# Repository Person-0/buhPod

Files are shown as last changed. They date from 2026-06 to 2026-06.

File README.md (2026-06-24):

# **buhPod**

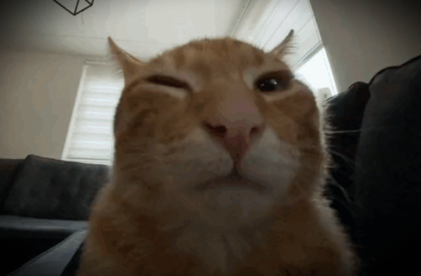
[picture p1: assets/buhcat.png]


A portable, battery-powered music player that supports 3.5mm wired earphones, made under 25$.

## Bill Of Materials
\> View [bom.csv](./bom.csv) (WIP)<br>
Total cost is **~25$**

## CAD Design
- WIP
- View [/CAD directoy](./cad/) for more information

> **Rough assembly**
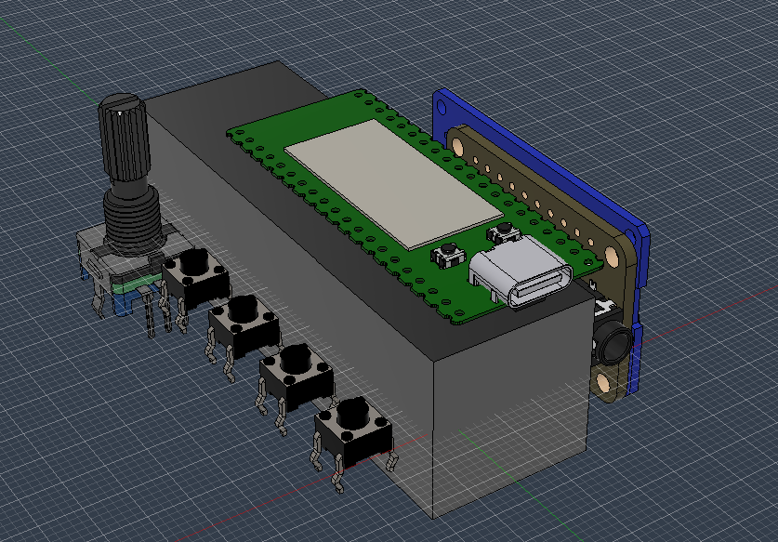
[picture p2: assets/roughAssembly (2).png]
> 

## Schematics

Done in KiCAD: [Schematics folder](./schematics/)

Since there is no PCB (these are all components wired/soldered together), there are no PCB files. <br>
However, you can still open the schematics in KiCAD, by:
- Opening KiCAD
- Clicking **File** (top left) >> **Open Project**
- Navigating to the the repository's saved destination,
- Opening **/schematics** directory
- Selecting the file `buhpod.kicad_pro`

This will open the schematics in KiCAD for easier viewing!<br>
The schematics are as follows:

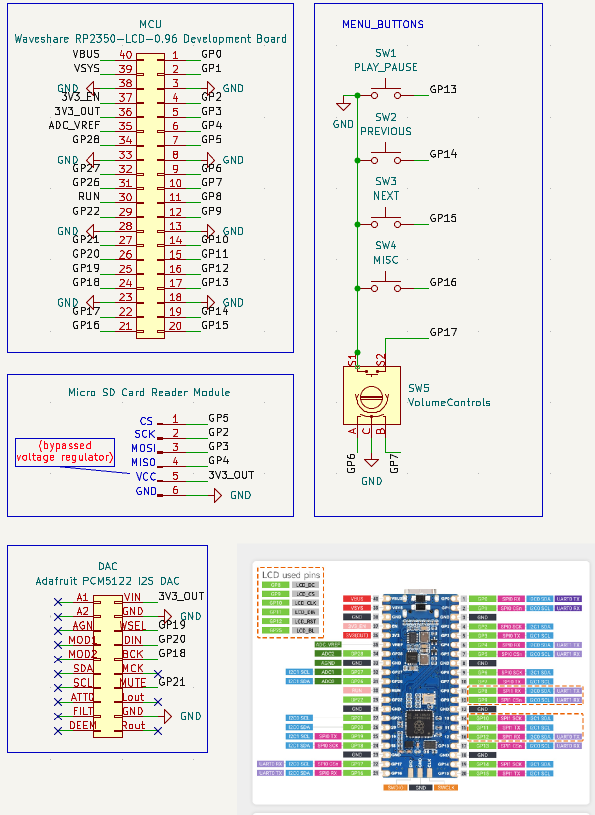
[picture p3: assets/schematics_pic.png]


### Micro SD card regulator bypass

The Micro SD card reader mentioned in the BOM requires **5V** input from **VCC**, but we can only supply **3.3V** from the MCU max as we are powering it via a 18650 3.7V battery and not USB.<br>

Hence, we need to bypass the voltage regulator present on board by powering the board from the following **3.3V pin**:

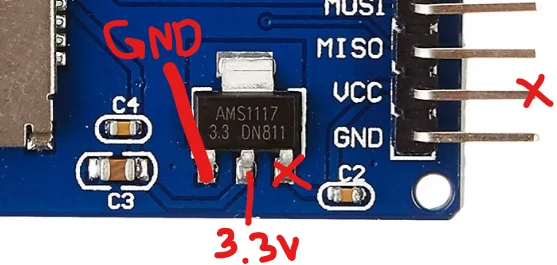
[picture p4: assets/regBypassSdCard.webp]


This bypasses the onboard AMS1117 voltage regulator and is connected to MCU's `3V3_OUT` pin.<br>
This is also mentioned in the schematic for the Micro SD Card reader.

## References
- https://www.waveshare.com/rp2350-lcd-0.96.htm
- https://files.waveshare.com/wiki/RP2350-LCD-0.96/RP2350_LCD_0.96_Schematic.pdf
- https://learn.adafruit.com/adafruit-pcm5122-i2s-dac/downloads
- https://www.instructables.com/Raspberry-Pi-Pico-Micro-SD-Card-Interface/  
- https://circuitdigest.com/microcontroller-projects/raspberry-pi-pico-interfacing-with-rotary-encoder
- https://www.instructables.com/Raspberry-Pi-Pico-and-Rotary-Encoder/

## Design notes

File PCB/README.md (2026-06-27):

# BuhPod PCB

- These are the PCB design files, made using KiCAD.<br>
- This is technically a fork of [Minimal design example](https://datasheets.raspberrypi.com/rp2350/Minimal-KiCAD.zip) provided by raspberrypi, in their [hardware design docs for the RP2350](https://pip-assets.raspberrypi.com/categories/1214-rp2350/documents/RP-008280-DS-1-hardware-design-with-rp2350.pdf).
- It is currently WIP.

## Credits / References
- https://pip-assets.raspberrypi.com/categories/1214-rp2350/documents/RP-008280-DS-1-hardware-design-with-rp2350.pdf
- https://deepbluembedded.com/rp2350-hardware-pcb-design-in-kicad-rp2350-schematic/
- https://macondo.hackclub.com/docs/build-a-devboard

## Licensing

The custom schematic and PCB layout files in this repository are licensed under the MIT License. 

This design is a derivative work based on the "Minimal Design Example" provided by Raspberry Pi Ltd. In accordance with their hardware terms, the reference templates are used solely in conjunction with Raspberry Pi silicon (RP2040/RP2350), and the original reference design is provided "AS IS" without any warranties.

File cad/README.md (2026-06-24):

## **buhPod** Design Files

> Everything was designed in Autodesk Fusion 360

## Rough Assembly

This is a **rough assembly** of components I made after hard labour. <br>
It is only for reference and will be enclosed in a cuboidal enclosure that is current work-in-progress.
> [Click to view **`roughAssembly.stl`**](./roughAssembly.stl)

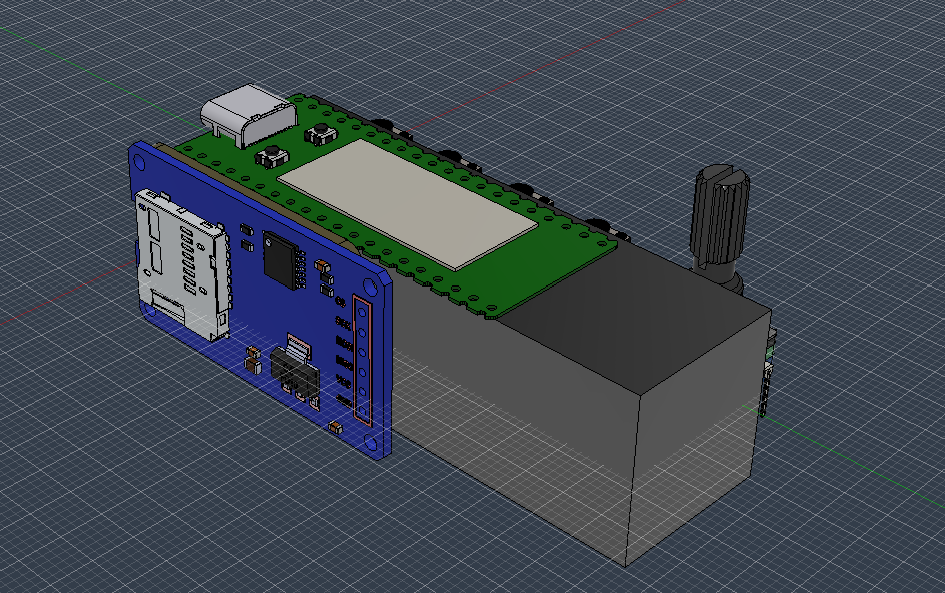
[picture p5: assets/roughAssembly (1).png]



### CAD Model Credits
- https://files.waveshare.com/wiki/RP2350-LCD-0.96/RP2350_LCD_0.96_STEP.zip
- https://grabcad.com/library/micro-sd-card-reader-module-1
- https://github.com/adafruit/Adafruit_CAD_Parts/blob/main/6421%20PCM5122%20I2S%20DAC/6421%20PCM5122%20I2S%20DAC.step
- https://grabcad.com/library/button-6x6x4-3-6x6x5-6x6x6-1
- https://grabcad.com/library/rotary-encoder-17

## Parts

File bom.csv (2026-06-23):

 |  | buhPod: BOM
 |  |  |  |  | (INR) |  | (INR)
S.No | Product Name | Product Description | Product Link | Product Info Link | Unit Price | Quantity | Running Total |  | CAD models
1 | Waveshare RP2350-LCD-0.96 Development Board | MCU (RP2350) with 0.96'' LCD display | https://robu.in/product/waveshare-rp2350-lcd-0-96-development-board-with-0-96inch-lcd-display-based-on-rp2350a-dual-core-dual-architecture-microcontroller/ | https://www.waveshare.com/rp2350-lcd-0.96.htm | 1066 | 1 | 1066 |  | https://files.waveshare.com/wiki/RP2350-LCD-0.96/RP2350_LCD_0.96_STEP.zip
2 | Micro SD Card Reader Module | SD Card reader module | https://robu.in/product/micro-sd-card-module/ |  | 33 | 1 | 33 |  | https://grabcad.com/library/micro-sd-card-reader-module-1
3 | ADAFRUIT PCM5122 I2S DAC WITH LI | PCM5122 I2S DAC | https://www.digikey.in/en/products/detail/adafruit-industries-llc/6421/27791955 | https://learn.adafruit.com/adafruit-pcm5122-i2s-dac/downloads | 708.83 | 1 | 708.83 |  | https://github.com/adafruit/Adafruit_CAD_Parts/blob/main/6421%20PCM5122%20I2S%20DAC/6421%20PCM5122%20I2S%20DAC.step
4 | LG INR18650MJ1 3400mAh (3c) LI-ION BATTERY | 18650 3400mAh 3.7v cell | https://robu.in/product/lg-18650-mj1-3400mah-3c-li-ion-battery/ | https://robu.in/product/lg-18650-mj1-3400mah-3c-li-ion-battery/ | 392 | 1 | 392 |  | 18mm x 65mm cylinder
5 | Tactile Push Button Switch 6x6x5 (Pack of 10) | Tactile buttons (momentary) | https://robu.in/product/6x6x5-tactile-push-button-switch/ | https://robu.in/product/6x6x5-tactile-push-button-switch/ | 15 | 1 | 15 |  | https://grabcad.com/library/button-6x6x4-3-6x6x5-6x6x6-1
6 | EC11 rotary encoder | EC11 rotary encoder | https://robu.in/product/hongyan-ec11h-7ce20p1zd20-rotary-encoder-with-push-button-switch-vertical-plug-in-5-pin/ | https://robu.in/product/hongyan-ec11h-7ce20p1zd20-rotary-encoder-with-push-button-switch-vertical-plug-in-5-pin/ | 52 | 1 | 52 | (already have) | https://grabcad.com/library/rotary-encoder-17
7 |  |  |  |  |  |  | 0
8 |  |  |  |  |  |  | 0
9 |  |  |  |  |  |  | 0
10 |  |  |  |  |  |  | 0
 |  |  |  |  |  |  | 0
 |  |  |  |  |  | Total: | 2266.83 | 23.93$
 |  |  |  |  |  |  |  | as of
 |  |  |  |  |  |  |  | 23-06-2026 22:10

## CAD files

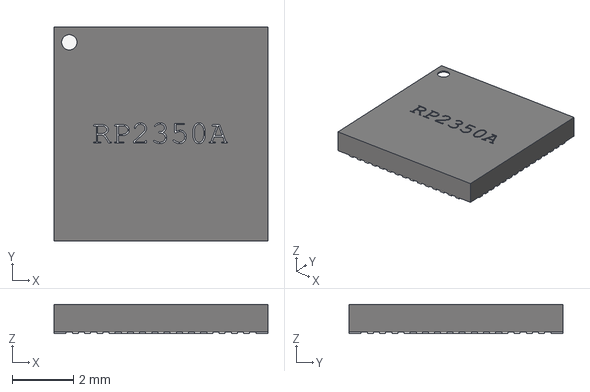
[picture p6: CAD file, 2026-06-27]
PCB/buhPod_PCB/RP2350_QFN60.step
7.00 x 7.00 x 0.95 mm

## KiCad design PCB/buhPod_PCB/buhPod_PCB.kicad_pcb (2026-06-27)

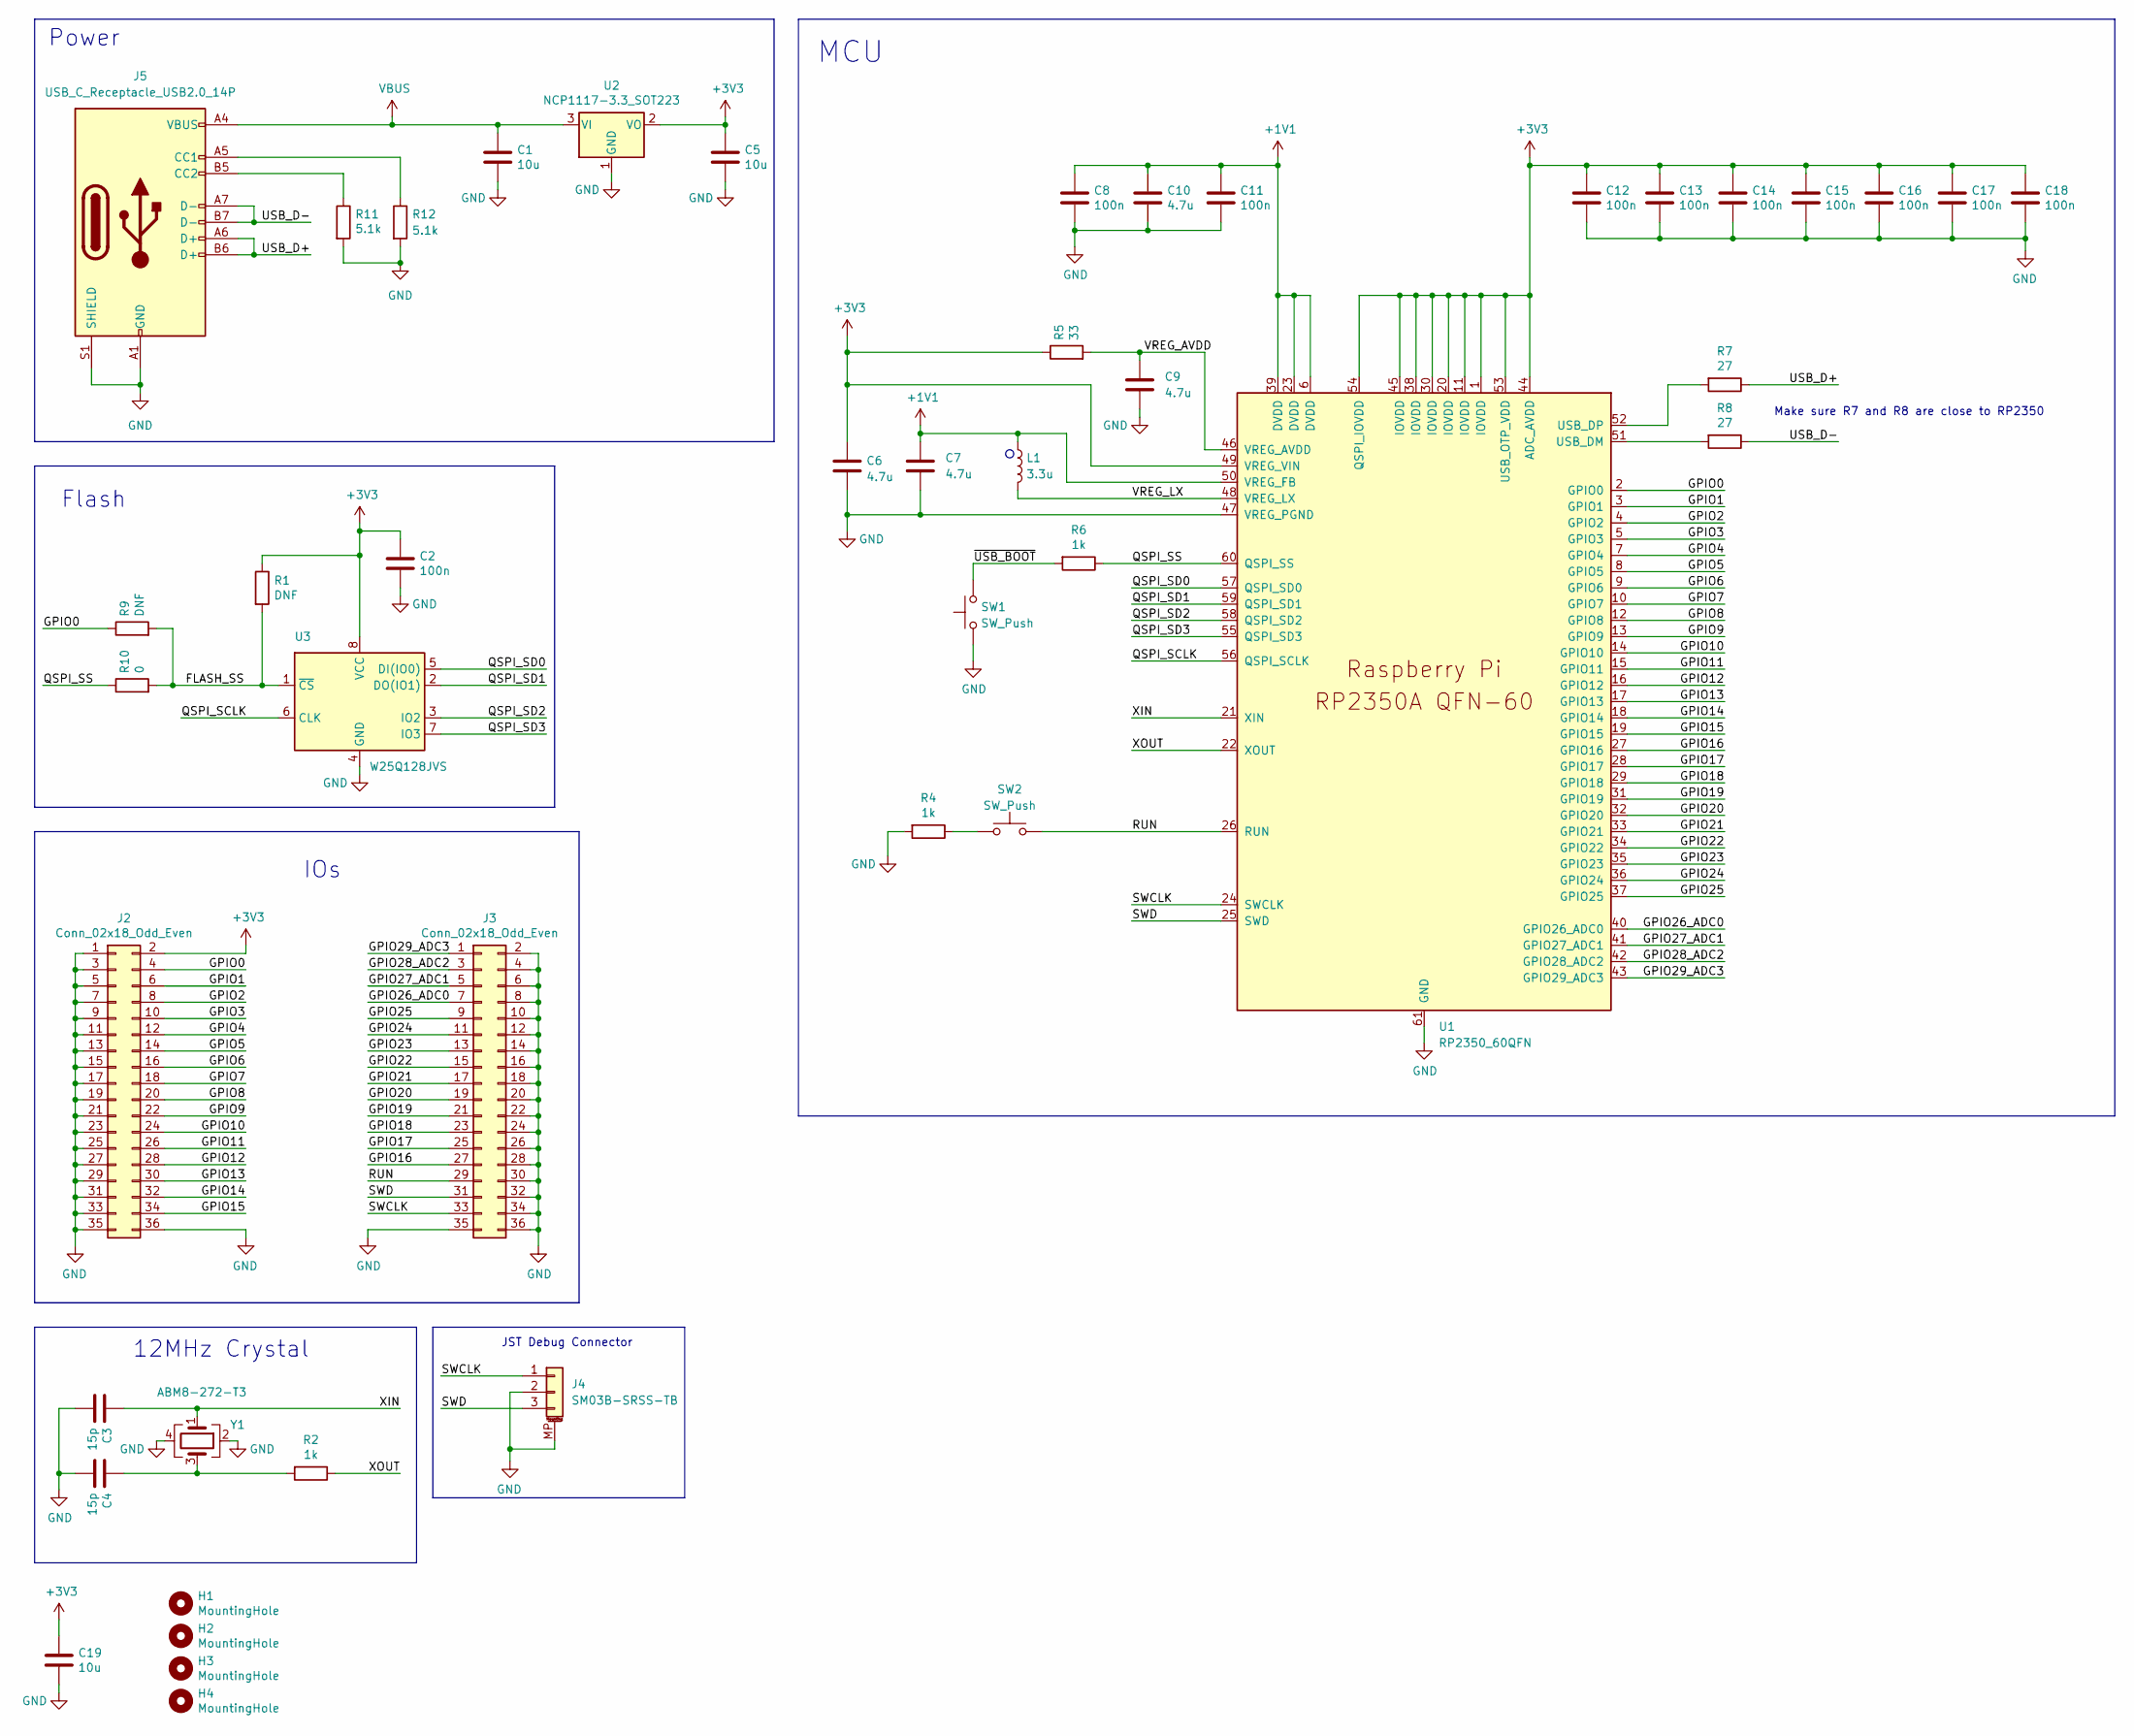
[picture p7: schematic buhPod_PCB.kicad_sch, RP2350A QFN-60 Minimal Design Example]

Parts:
C1, C5, C19: 10u; C_0805_2012Metric
C2, C8, C11, C12, C13, C14, C15, C16, C17, C18: 100n; C_0402_1005Metric
C3, C4: 15p; C_0402_1005Metric
C6, C7: 4.7u; C_0402_1005Metric_small_pads
C9, C10: 4.7u; C_0402_1005Metric
H1, H2, H3, H4: MountingHole; MountingHole_2.7mm_M2.5
J2, J3: Conn_02x18_Odd_Even; PinHeader_2x18_P2.54mm_Vertical
J4: SM03B-SRSS-TB; JST_SH_SM03B-SRSS-TB_1x03-1MP_P1.00mm_Horizontal
J5: USB_C_Receptacle_USB2.0_14P; USB_C_Receptacle_Amphenol_124019772112A
L1: 3.3u; L_pol_2016
R1, R9: DNF; R_0402_1005Metric
R2, R4, R6: 1k; R_0402_1005Metric
R5: 33; R_0402_1005Metric
R7, R8: 27; R_0402_1005Metric
R10: 0; R_0402_1005Metric
R11, R12: 5.1k; R_0402_1005Metric
SW1, SW2: SW_Push; SW_Push_1P1T_NO_Vertical_Wuerth_434133025816
U1: RP2350_60QFN; RP2350-QFN-60-1EP_7x7_P0.4mm_EP3.4x3.4mm_ThermalVias
U2: NCP1117-3.3_SOT223; SOT-223-3_TabPin2
U3: W25Q128JVS; SOIC-8_5.23x5.23mm_P1.27mm
Y1: ABM8-272-T3; Crystal_SMD_3225-4Pin_3.2x2.5mm

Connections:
+1V1: C7.1, C8.1, C10.1, C11.1, L1.1, U1.6 (DVDD), U1.23 (DVDD), U1.39 (DVDD), U1.50 (VREG_FB)
+3V3: C2.1, C5.1, C6.1, C12.1, C13.1, C14.1, C15.1, C16.1, C17.1, C18.1, C19.1, J2.2, R1.1, R5.1, U1.1 (IOVDD), U1.11 (IOVDD), U1.20 (IOVDD), U1.30 (IOVDD), U1.38 (IOVDD), U1.44 (ADC_AVDD), U1.45 (IOVDD), U1.49 (VREG_VIN), U1.53 (USB_OTP_VDD), U1.54 (QSPI_IOVDD), U2.2 (VO), U3.8 (VCC)
/FLASH_SS: R1.2, R9.2, R10.2, U3.1 (~CS)
/GPIO0: J2.4, R9.1, U1.2 (GPIO0)
/GPIO1: J2.6, U1.3 (GPIO1)
/GPIO2: J2.8, U1.4 (GPIO2)
/GPIO3: J2.10, U1.5 (GPIO3)
/GPIO4: J2.12, U1.7 (GPIO4)
/GPIO5: J2.14, U1.8 (GPIO5)
/GPIO6: J2.16, U1.9 (GPIO6)
/GPIO7: J2.18, U1.10 (GPIO7)
/GPIO8: J2.20, U1.12 (GPIO8)
/GPIO9: J2.22, U1.13 (GPIO9)
/GPIO10: J2.24, U1.14 (GPIO10)
/GPIO11: J2.26, U1.15 (GPIO11)
/GPIO12: J2.28, U1.16 (GPIO12)
/GPIO13: J2.30, U1.17 (GPIO13)
/GPIO14: J2.32, U1.18 (GPIO14)
/GPIO15: J2.34, U1.19 (GPIO15)
/GPIO16: J3.27, U1.27 (GPIO16)
/GPIO17: J3.25, U1.28 (GPIO17)
/GPIO18: J3.23, U1.29 (GPIO18)
/GPIO19: J3.21, U1.31 (GPIO19)
/GPIO20: J3.19, U1.32 (GPIO20)
/GPIO21: J3.17, U1.33 (GPIO21)
/GPIO22: J3.15, U1.34 (GPIO22)
/GPIO23: J3.13, U1.35 (GPIO23)
/GPIO24: J3.11, U1.36 (GPIO24)
/GPIO25: J3.9, U1.37 (GPIO25)
/GPIO26_ADC0: J3.7, U1.40 (GPIO26_ADC0)
/GPIO27_ADC1: J3.5, U1.41 (GPIO27_ADC1)
/GPIO28_ADC2: J3.3, U1.42 (GPIO28_ADC2)
/GPIO29_ADC3: J3.1, U1.43 (GPIO29_ADC3)
/QSPI_SCLK: U1.56 (QSPI_SCLK), U3.6 (CLK)
/QSPI_SD0: U1.57 (QSPI_SD0), U3.5 (DI(IO0))
/QSPI_SD1: U1.59 (QSPI_SD1), U3.2 (DO(IO1))
/QSPI_SD2: U1.58 (QSPI_SD2), U3.3 (IO2)
/QSPI_SD3: U1.55 (QSPI_SD3), U3.7 (IO3)
/QSPI_SS: R6.1, R10.1, U1.60 (QSPI_SS)
/RUN: J3.29, SW2.2, U1.26 (RUN)
/SWCLK: J3.33, J4.1, U1.24 (SWCLK)
/SWD: J3.31, J4.3, U1.25 (SWD)
/USB_D+: J5.A6 (D+), J5.B6 (D+), R7.1; also elsewhere on the board
/USB_D-: J5.A7 (D-), J5.B7 (D-), R8.1; also elsewhere on the board
/VREG_AVDD: C9.1, R5.2, U1.46 (VREG_AVDD)
/VREG_LX: L1.2, U1.48 (VREG_LX)
/XIN: C3.1, U1.21 (XIN), Y1.1
/XOUT: R2.1, U1.22 (XOUT)
/~USB_BOOT: R6.2, SW1.2
GND: C1.2, C2.2, C3.2, C4.2, C5.2, C6.2, C7.2, C8.2, C9.2, C10.2, C11.2, C12.2, C13.2, C14.2, C15.2, C16.2, C17.2, C18.2, C19.2, J2.1, J2.3, J2.5, J2.7, J2.9, J2.11, J2.13, J2.15, J2.17, J2.19, J2.21, J2.23, J2.25, J2.27, J2.29, J2.31, J2.33, J2.35, J2.36, J3.2, J3.4, J3.6, J3.8, J3.10, J3.12, J3.14, J3.16, J3.18, J3.20, J3.22, J3.24, J3.26, J3.28, J3.30, J3.32, J3.34, J3.35, J3.36, J4.2, J4.MP (MountPin), J5.A1 (GND), J5.A12 (GND), J5.B1 (GND), J5.B12 (GND), J5.S1 (SHIELD), R4.2, R11.2, R12.2, SW1.1, U1.47 (VREG_PGND), U1.61 (GND), U2.1 (GND), U3.4 (GND), Y1.2, Y1.4; also elsewhere on the board
unnamed: C4.1, R2.2, Y1.3
unnamed: J5.A5 (CC1), R12.1
unnamed: J5.B5 (CC2), R11.1
unnamed: R4.1, SW2.1
unnamed: R8.2, U1.51 (USB_DM)
unnamed: R7.2, U1.52 (USB_DP)
VBUS: C1.1, J5.A4 (VBUS), J5.A9 (VBUS), J5.B4 (VBUS), J5.B9 (VBUS), U2.3 (VI); also elsewhere on the board

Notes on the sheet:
JST Debug Connector
IOs
Flash
Make sure R7 and R8 are close to RP2350
MCU
12MHz Crystal
Power

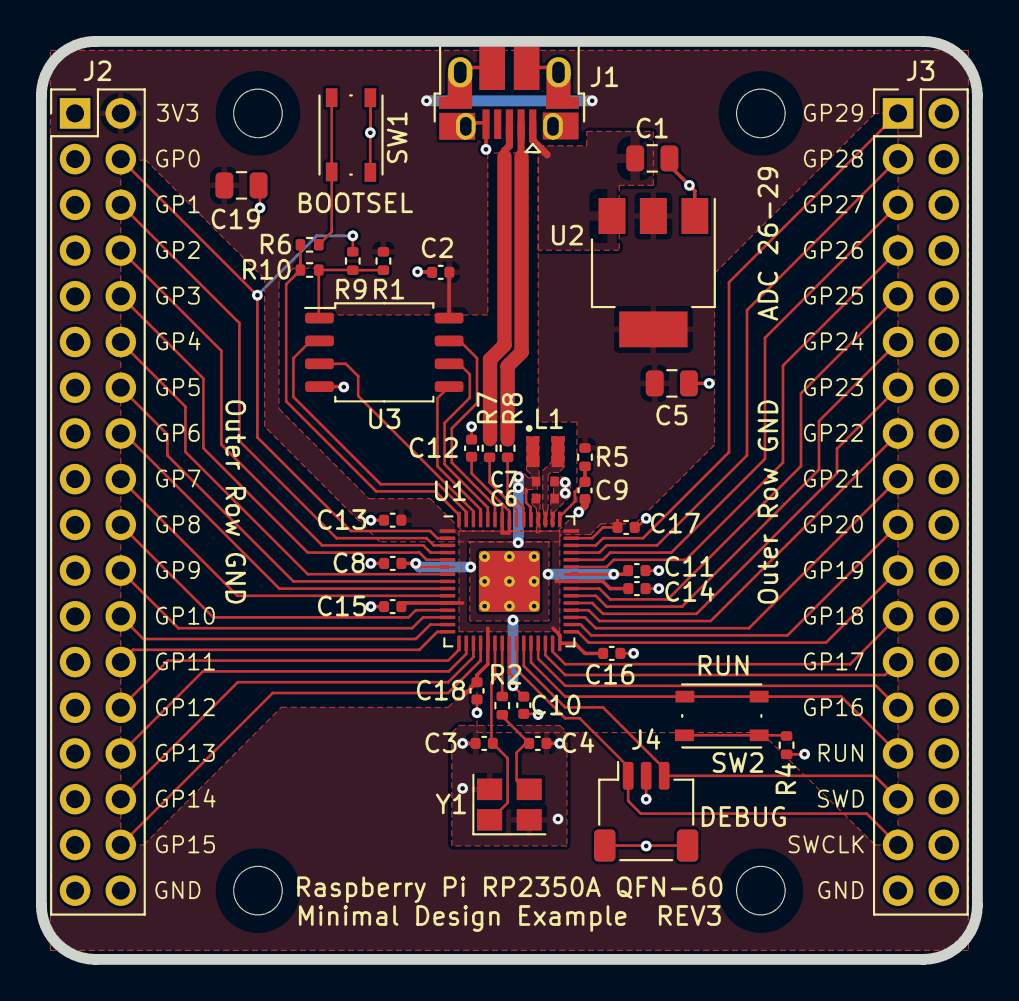
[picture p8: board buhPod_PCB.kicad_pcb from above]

Board: 2 copper layers, 52.0 x 51.0 mm, 43 parts (0 on the bottom side), 55 nets.

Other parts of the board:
J1: USB_B_Micro; USB_Micro-B_Amphenol_10103594-0001LF_Horizontal

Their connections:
/USB_D+: J1.3 (D+); also elsewhere on the board
/USB_D-: J1.2 (D-); also elsewhere on the board
GND: J1.5 (GND), J1.6 (Shield); also elsewhere on the board
VBUS: J1.1 (VBUS); also elsewhere on the board

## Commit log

2026-06-23 not using pcb for this
2026-06-23 updated bom
    [bom.csv]
2026-06-23 done schematics
    [buhpod.kicad_pcb, buhpod.kicad_sch]
2026-06-23 updated readme w schematics
2026-06-23 schematics viewing explanation
2026-06-23 added devboard schematic reference
2026-06-24 added rough assembly
2026-06-24 added rough assembly pic to main readme
2026-06-24 added misc btn
    [buhpod.kicad_sch]
2026-06-24 added rough assembly stl file
2026-06-24 bom is wip
2026-06-27 pcb redo init
    [RP2350_QFN60.step, buhPod_PCB.kicad_pcb, buhPod_PCB.kicad_sch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]
